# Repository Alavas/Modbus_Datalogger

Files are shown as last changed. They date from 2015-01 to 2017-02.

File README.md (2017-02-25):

# Modbus_Datalogger

Web based data logger.

This device can communicate with any of the Grundfos E-Products through a ModBus interface. Currently it the programming is optimized to work with the Magna3 product line. The Parallax Propeller receives the ModBus data over RS485 and then does the decoding and unit conversion of the pump data. The Electric Imp (SD card shape) polls the Propeller for the new data and then adds its own data. The Electric Imp currently has 3 external thermistors as well as its on board light sensor. This data is packaged on the device and send on to the Electric Imp agent(https://electricimp.com/docs/api/agent/). The Imp agent then breaks up the data and sends the requested data to the Phant(http://phant.io/about/) data server. The server exists currently on a Amazon Web Services EC2 Micro Instance Linux server. In order to view the data a web page interface is used. This web page uses Google Charts to display data from the Phant server. Additional static information is displayed at the bottom of the web page, this information is grabbed from the Electric Imp agent.

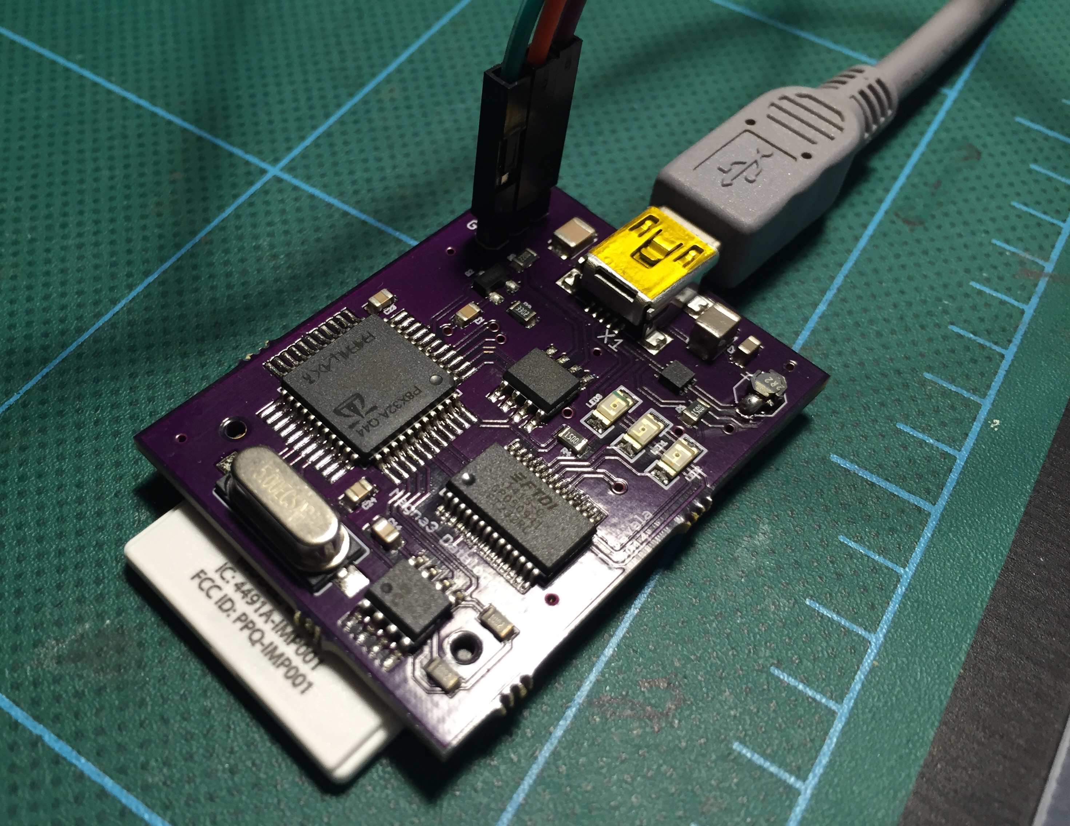
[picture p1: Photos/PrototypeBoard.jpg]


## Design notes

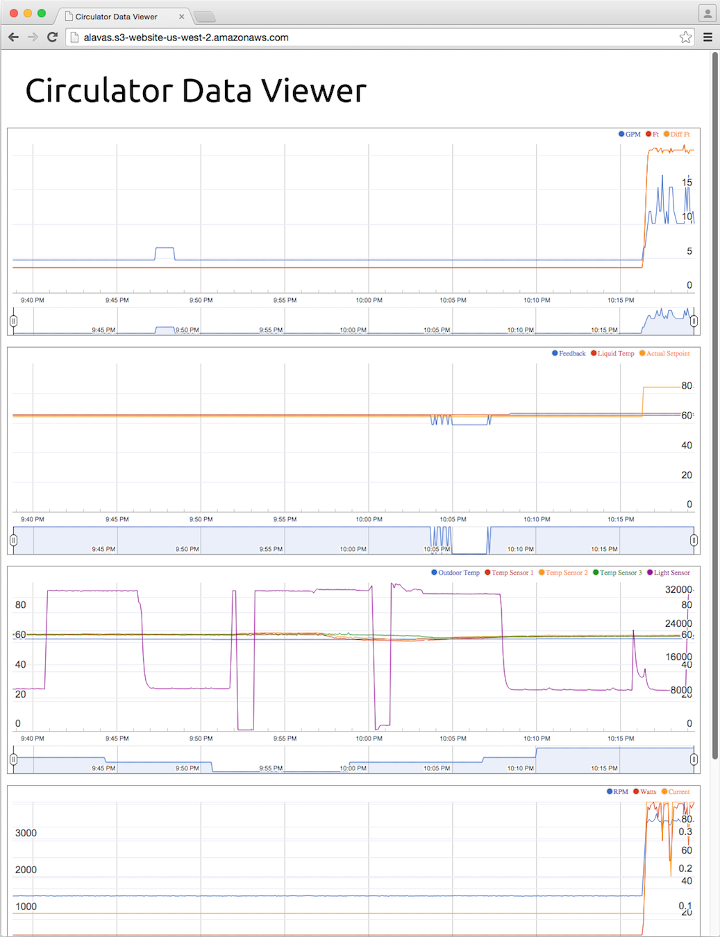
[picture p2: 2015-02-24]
Photos/Web Viewer.png

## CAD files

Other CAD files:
Drawing/Enclosure.skp
Drawing/Lid.skp

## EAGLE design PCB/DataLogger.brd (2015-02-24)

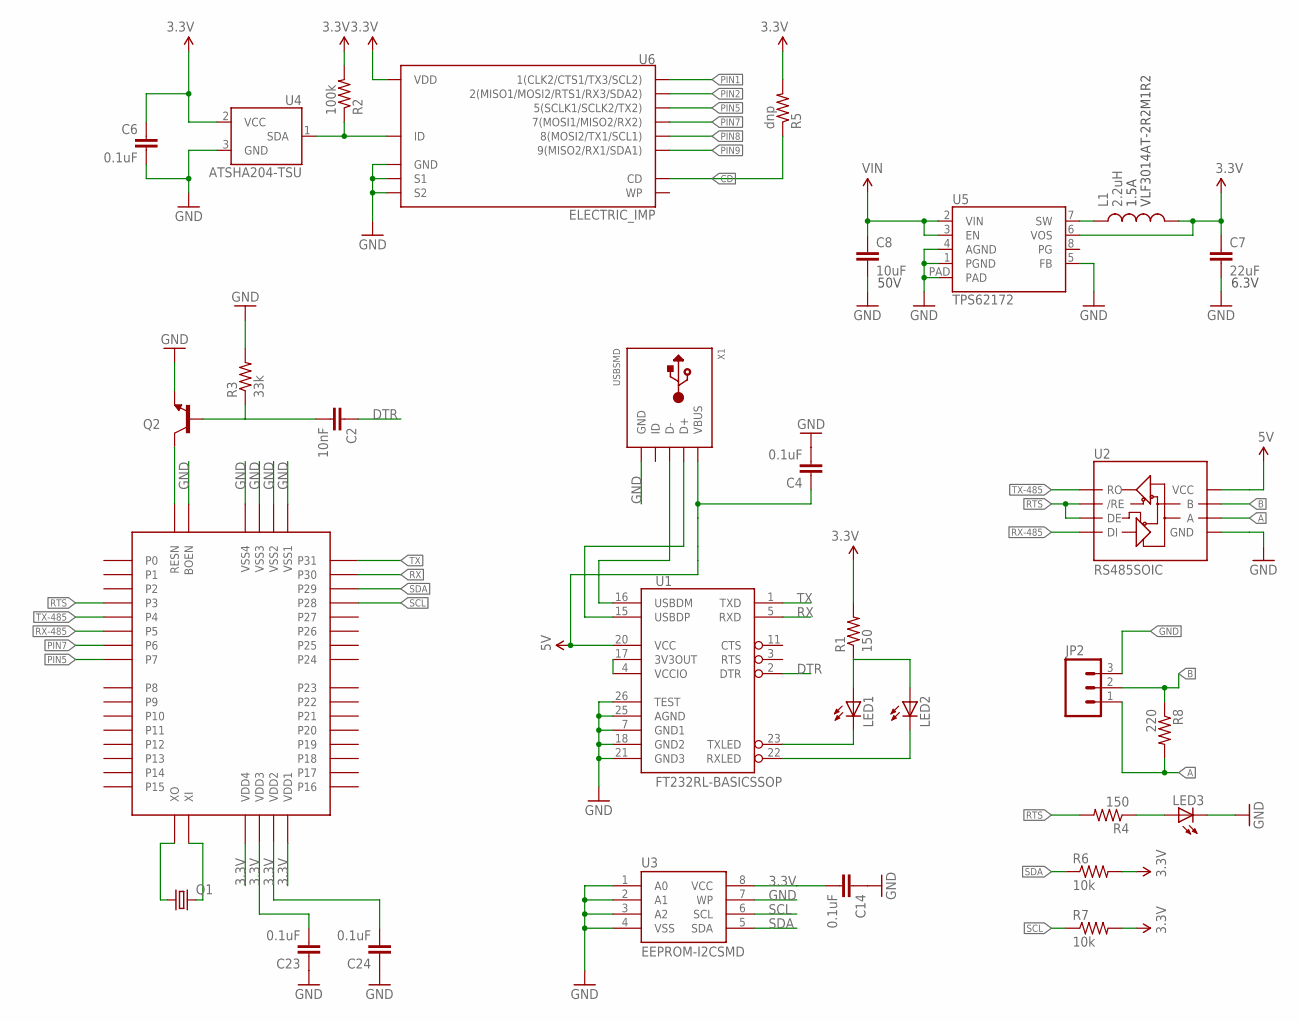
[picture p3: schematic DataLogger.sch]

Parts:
C2: 10nF; 0805
C4: 0.1uF; 1210
C6: 0.1uF; 0603-CAP
C7: 22uF; 0805
C8: 10uF; 1210
C14, C23, C24: 0.1uF; 0805
JP2: M03PTH; 1X03
L1: 2.2uH; VLF4012A
LED1, LED2, LED3: LED1206; LED-1206
Q1: CRYSTALSM49; SM49
Q2: TRANSISTOR_NPNSOT23; SOT23
R1, R4: 150; 0805
R2: 100k; 0603-RES
R3: 33k; 0805
R5: dnp; 0603-RES
R6, R7: 10k; 0805
R8: 220; 0805
U1: FT232RL-BASICSSOP; SSOP28DB
U2: RS485SOIC; SO08
U3: EEPROM-I2CSMD; SO08
U4: ATSHA204-TSU; SOT23-3
U5: TPS62172; WSON-8-PAD
U6: ELECTRIC_IMP; SD_1:1
U7: PROPELLERSURFACELQFP; SURFACEMOUNT
X1: USBSMD; USB-MINIB

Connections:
3.3V: C6.1, C7.1, C14.2, C23.2, C24.2, L1.P$2 (2), R1.2, R2.2, R5.2, R6.2, R7.2, U3.8 (VCC), U4.2 (VCC), U5.6 (VOS), U6.4 (VDD), U7.8 (VDD1), U7.18 (VDD2), U7.30 (VDD3), U7.40 (VDD4)
5V: C4.1, C8.1, U1.20 (VCC), U2.8 (VCC), U5.2 (VIN), U5.3 (EN), X1.VBUS
A: JP2.1, R8.2, U2.6 (A)
B: JP2.2, R8.1, U2.7 (B)
CD: R5.1, U6.CD
DTR: C2.1, C2.2, Q2.1 (B), R3.1, U1.2 (DTR)
GND: C4.2, C6.2, C7.2, C8.2, C14.1, C23.1, C24.1, JP2.3, LED3.C, Q2.2 (E), R3.2, U1.7 (GND1), U1.18 (GND2), U1.21 (GND3), U1.25 (AGND), U1.26 (TEST), U2.5 (GND), U3.1 (A0), U3.2 (A1), U3.3 (A2), U3.4 (VSS), U3.7 (WP), U4.3 (GND), U5.1 (PGND), U5.4 (AGND), U5.5 (FB), U5.PAD, U6.3 (GND), U6.SH@1 (S1), U6.SH@2 (S2), U7.5 (VSS1), U7.6 (BOEN), U7.17 (VSS2), U7.27 (VSS3), U7.39 (VSS4), X1.GND
ID: R2.1, U4.1 (SDA), U6.6 (ID)
unnamed: U1.16 (USBDM), X1.D-
unnamed: U1.15 (USBDP), X1.D+
unnamed: Q2.3 (C), U7.7 (RESN)
unnamed: U1.4 (VCCIO), U1.17 (3V3OUT)
unnamed: Q1.2, U7.28 (XI)
unnamed: Q1.1, U7.29 (XO)
unnamed: L1.P$1 (1), U5.7 (SW)
unnamed: LED1.C, U1.23 (TXLED)
unnamed: LED2.C, U1.22 (RXLED)
unnamed: LED1.A, LED2.A, R1.1
unnamed: LED3.A, R4.1
PIN1: U6.1 (1(CLK2/CTS1/TX3/SCL2))
PIN2: U6.2 (2(MISO1/MOSI2/RTS1/RX3/SDA2))
PIN5: U6.5 (5(SCLK1/SCLK2/TX2)), U7.4 (P7)
PIN7: U6.7 (7(MOSI1/MISO2/RX2)), U7.3 (P6)
PIN8: U6.8 (8(MOSI2/TX1/SCL1))
PIN9: U6.9 (9(MISO2/RX1/SDA1))
RTS: R4.2, U2.2 (/RE), U2.3 (DE), U7.44 (P3)
RX: U1.5 (RXD), U7.37 (P30)
RX-485: U2.4 (DI), U7.2 (P5)
SCL: R7.1, U3.6 (SCL), U7.35 (P28)
SDA: R6.1, U3.5 (SDA), U7.36 (P29)
TX: U1.1 (TXD), U7.38 (P31)
TX-485: U2.1 (RO), U7.1 (P4)

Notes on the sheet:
50V
6.3V
1.5A
VLF3014AT-2R2M1R2

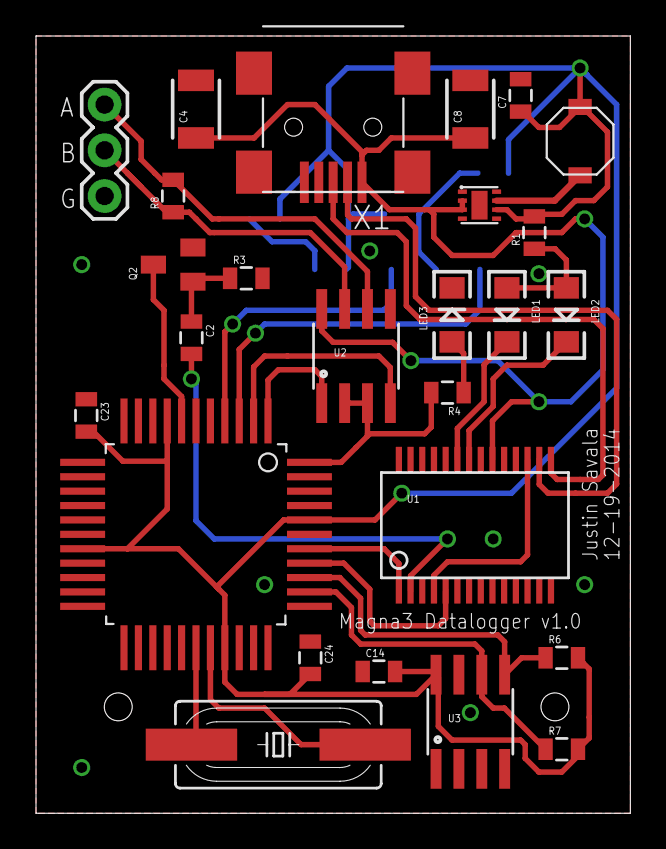
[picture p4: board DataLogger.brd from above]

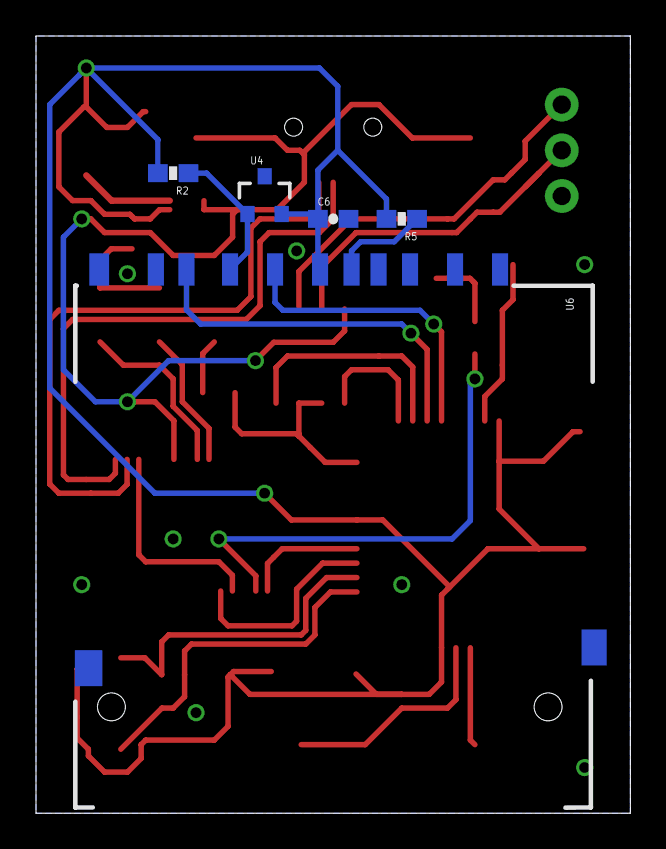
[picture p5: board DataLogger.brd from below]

Board: 2 copper layers, 33.0 x 43.2 mm, 31 parts (5 on the bottom side), 28 nets.

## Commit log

2015-01-28 Added Propeller Program files.
2015-02-23 Added enclosure drawings.
    [Enclosure.skp, Lid.skp]
2015-02-24 Added PCB files.
    [DataLogger.brd, DataLogger.sch]

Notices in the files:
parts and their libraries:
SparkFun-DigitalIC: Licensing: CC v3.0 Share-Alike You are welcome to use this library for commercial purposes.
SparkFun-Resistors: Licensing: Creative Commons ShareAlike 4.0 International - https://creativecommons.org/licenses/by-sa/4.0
